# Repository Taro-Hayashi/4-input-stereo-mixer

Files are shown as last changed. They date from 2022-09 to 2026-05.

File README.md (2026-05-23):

# 4入力ステレオミキサー ビルドガイド
- [ご注意](#ご注意)
- [部品リスト](#部品リスト)
- [組み立て](#組み立て)
- [おまけ](#おまけ)
- [ライセンス](#ライセンス)

## ご注意
- Type-A to Type-Cケーブルでのみ給電できます。
- ボリューム調整機能はありません。
- マイクには対応していません。
- 入力端子同士の間隔は1.2cmです。

## 部品リスト
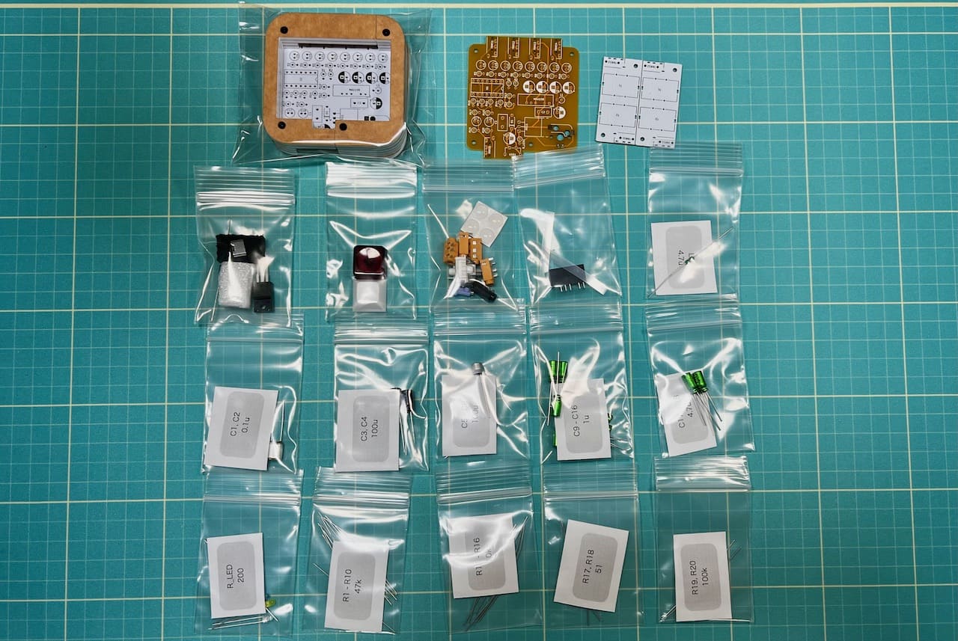
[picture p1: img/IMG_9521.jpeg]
  
|Ref|部品名|数|
|-|-|-|
||メインボード||
||アクリルプレート||
||0.01mm両面テープ||
||5mmM2ねじ|8|
||3x8mmスペーサー|4|
|U1|丸ピンICソケット 14P|1|
||オペアンプ LME49740NA|1|
|MAU108|レギュレーター MAU108|1|
|REG1|レギュレーター NJM7805FA|1|
|USB1|Type-Cコネクタ電源供給用|1|
|TRRS1-5|MJ-4PP-9|5|
|R1-10|47kΩ|10|
|R11-16|10kΩ|6|
|R11-16|10kΩ|6|
|R17,18|51Ω|2|
|R19,20|100kΩ|2|
|R_LED|200Ω|1|
|C1,2|0.1uF フィルムコンデンサー|2|
|C3,4|100uF 電源用電解コンデンサー|2|
|C5-8|100uF OS-CON|4|
|C9-16|1uF オーディオ用無極性コンデンサー|8|
|C17,18|4.7uF オーディオ用無極性コンデンサー|2|
|D1|1N4007|1|
|L1|4.7uH|1|
|LED1|3mmLED 3V 20mA|1|
||キースイッチ|1|
||キーキャップ|1|
||スイッチソケット|1|
||ゴム足|4|

### 工具（必要に応じて準備してください）
|工具名||
|-|-|
|はんだ付け用工具一式||
|精密ドライバー||
|ニッパー|抵抗等の足を切ります。|
|ラジオペンチ|レギュレーターの足を曲げます。ニッパーでも可能です。|
|アクリサンデー ポリケアF70|指紋を拭いたりホコリを付きにくくできます。|
|アクリサンデー 研磨剤|側面を磨いてツルツルにしたり、細かい傷を消すことができます。|
|アクリル接着剤|両面テープの代わりに使うと強固に接着できます。|

## 組み立て
電子部品は番号通りに部品をはんだ付けするだけなのでビルドガイドを見なくても制作可能です。高さが低い順番にはんだ付けする様子を写真で紹介しています。  

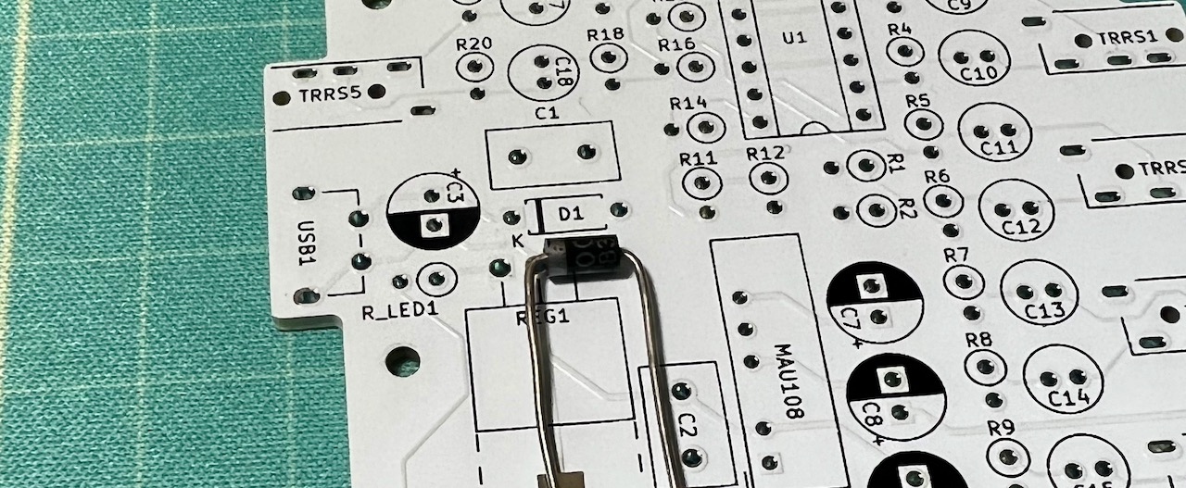
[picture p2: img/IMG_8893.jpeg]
  
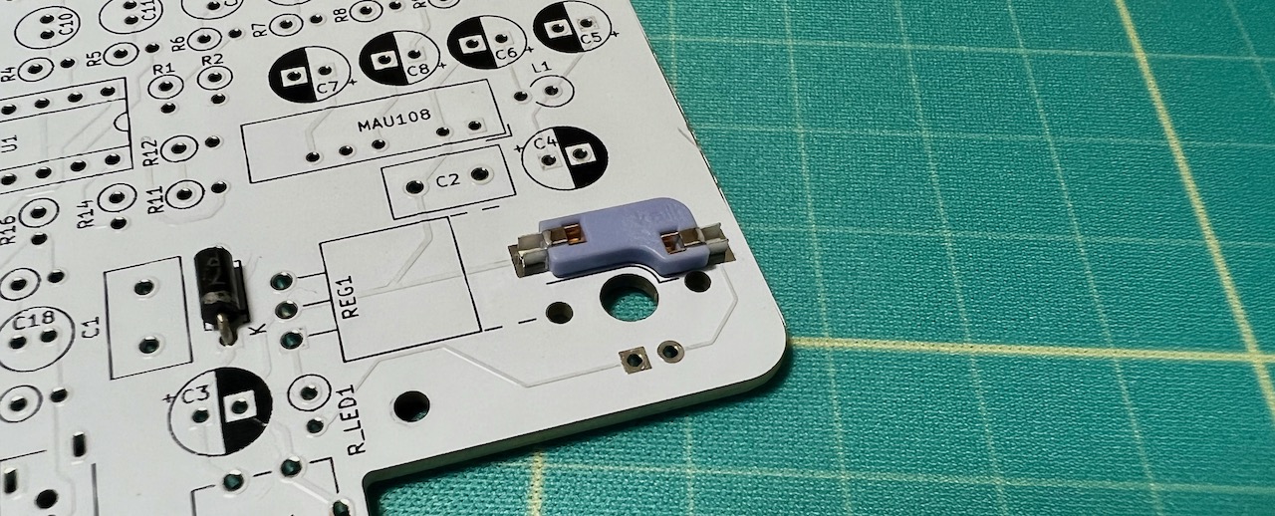
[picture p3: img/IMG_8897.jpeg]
  
Type-Cコネクタはマスキングテープなどで固定するとはんだ付けしやすいです。
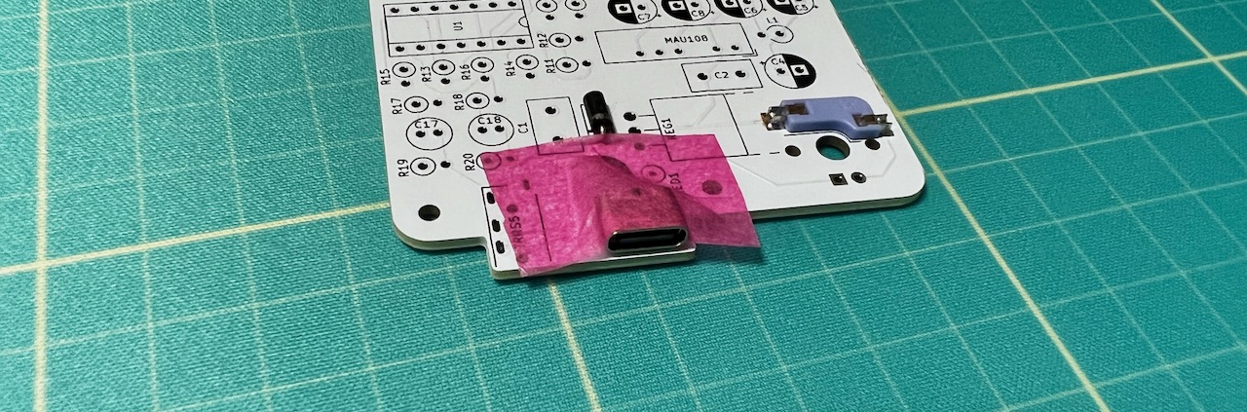
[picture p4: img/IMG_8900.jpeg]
  
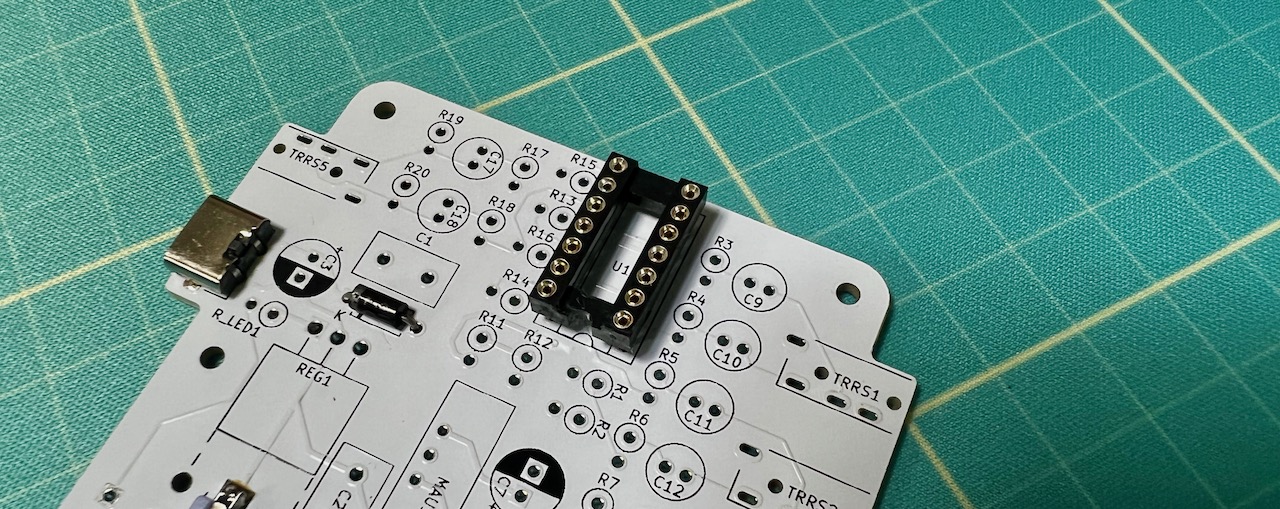
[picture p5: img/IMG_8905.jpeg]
  
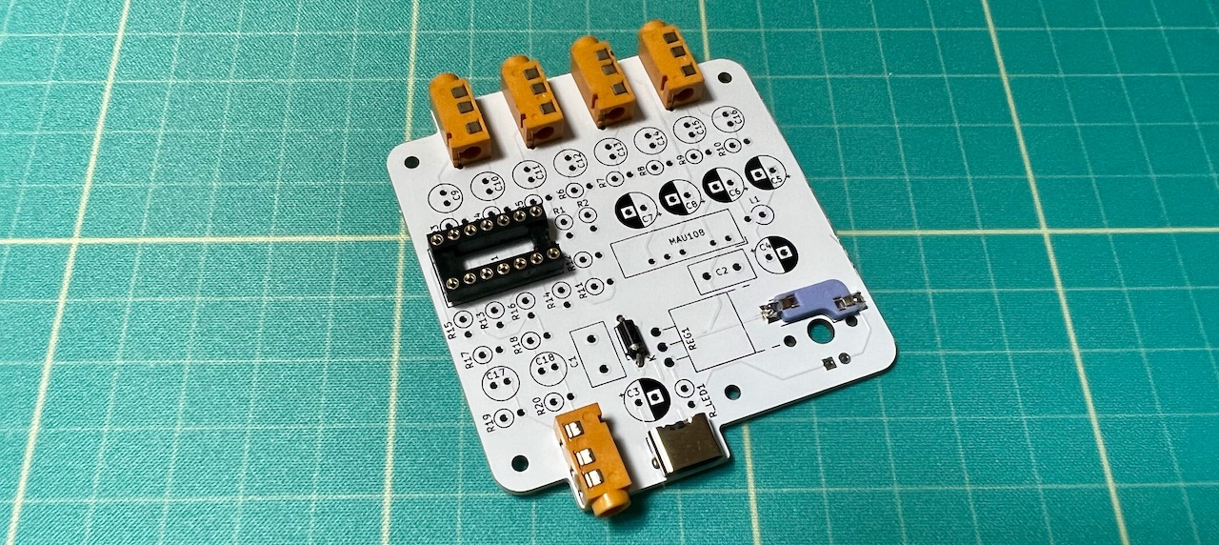
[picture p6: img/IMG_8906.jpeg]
  
OS-CONには極性があります。足が長い方が+（白い側）です。  
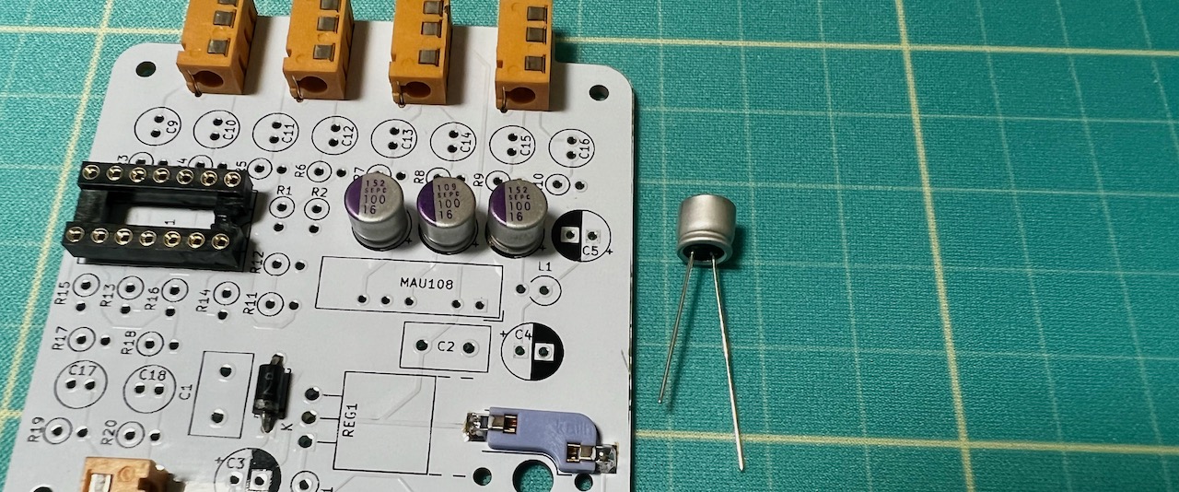
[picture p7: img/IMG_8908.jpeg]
  
レギュレーターの足をラジオペンチ等で曲げます。
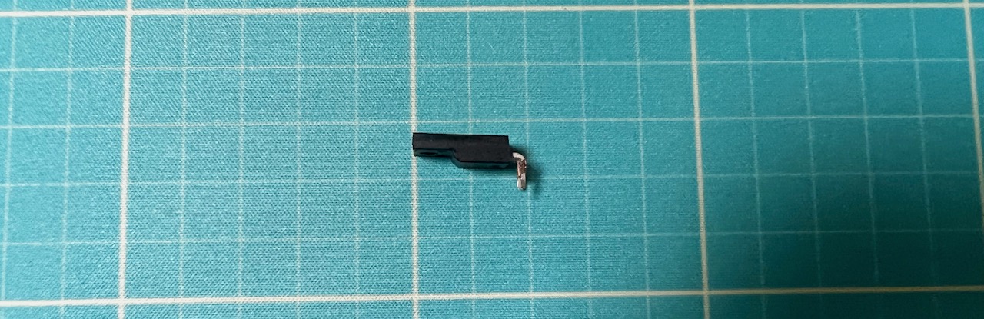
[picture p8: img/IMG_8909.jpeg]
  
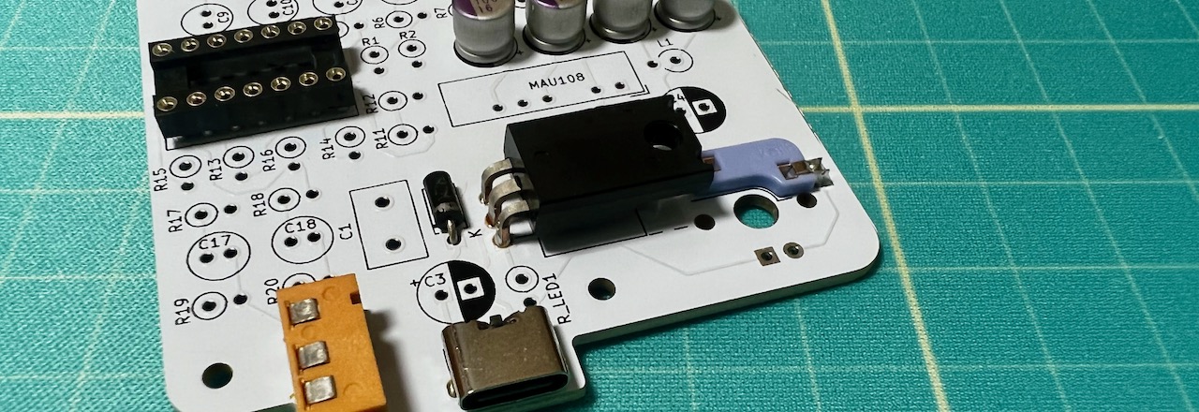
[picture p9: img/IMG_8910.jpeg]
  
コイルや抵抗は写真のように足を曲げて縦に取り付けます。
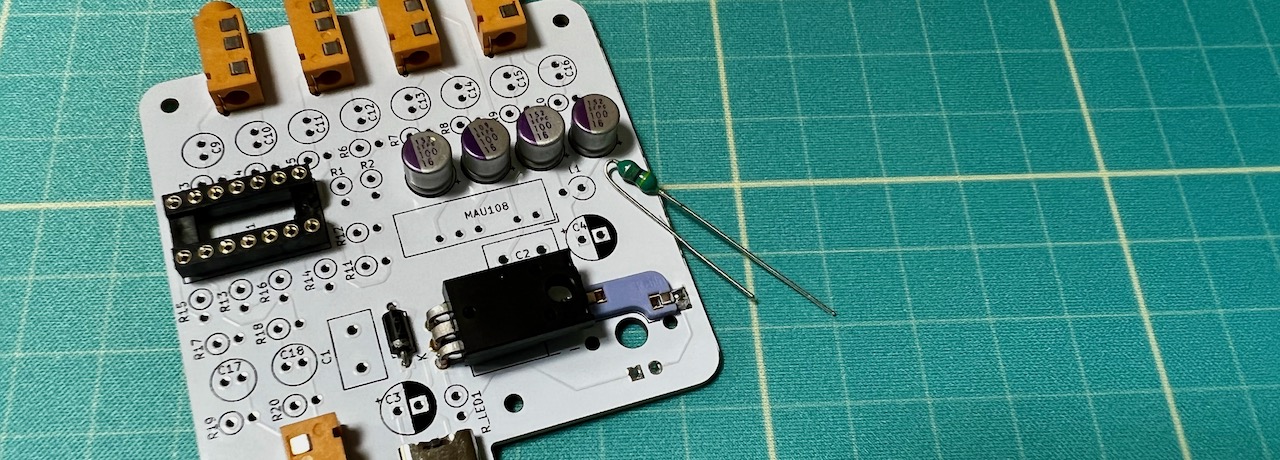
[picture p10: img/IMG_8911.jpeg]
  
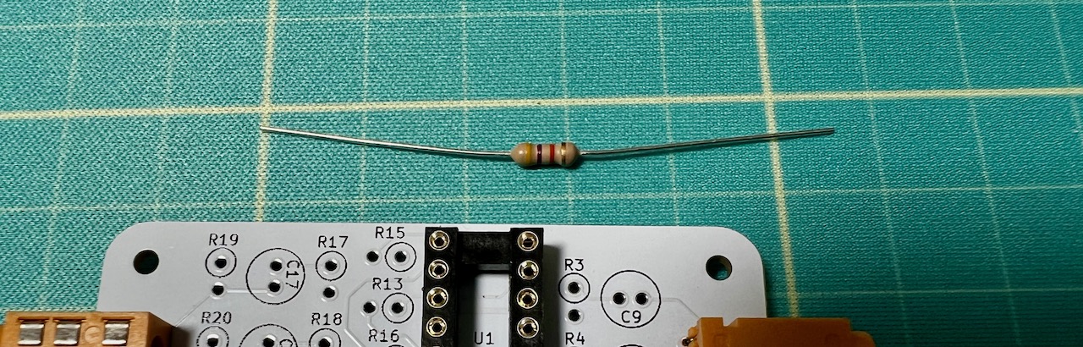
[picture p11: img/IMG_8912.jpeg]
  
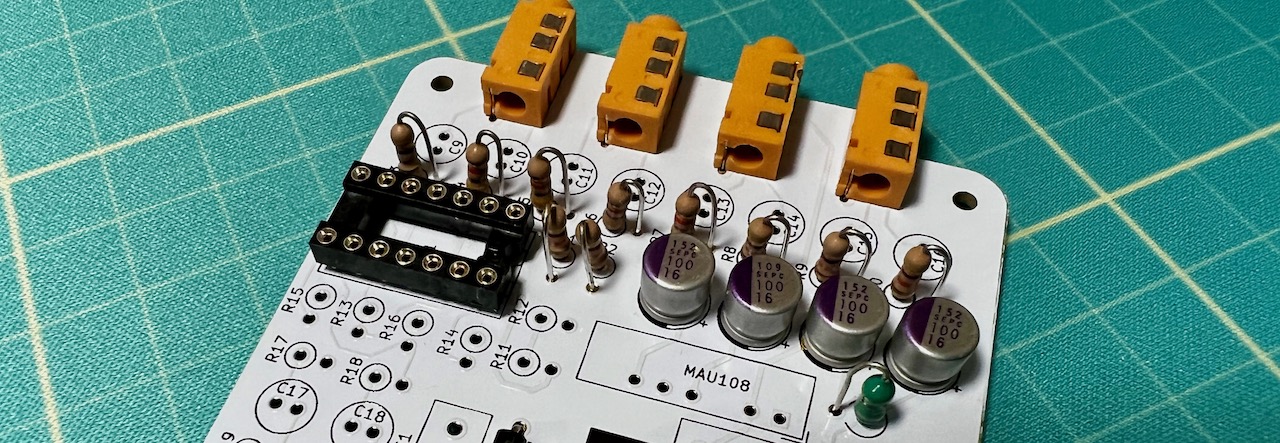
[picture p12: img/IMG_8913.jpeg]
  
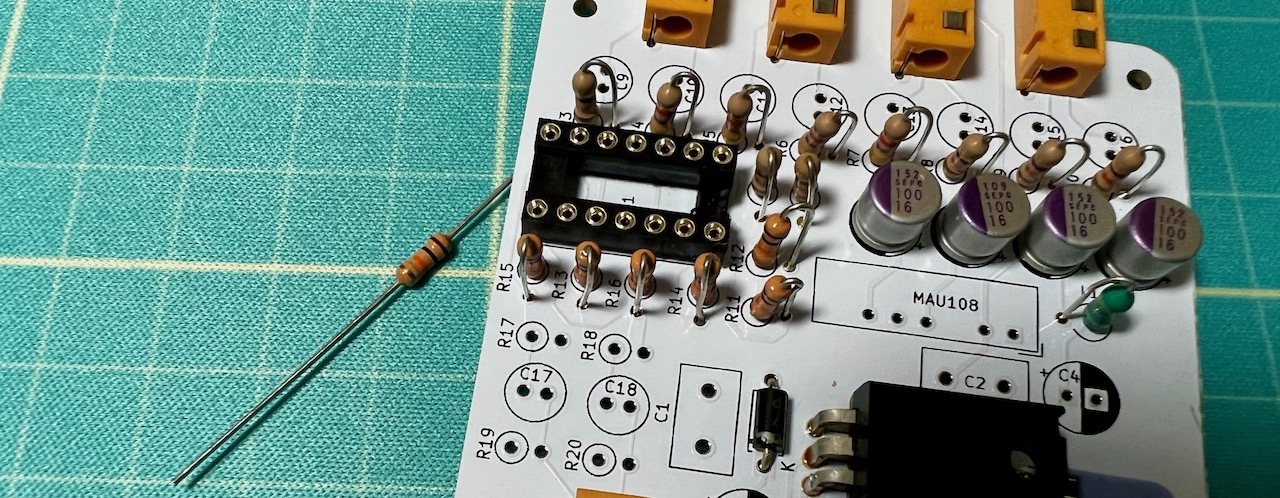
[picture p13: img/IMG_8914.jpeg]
  
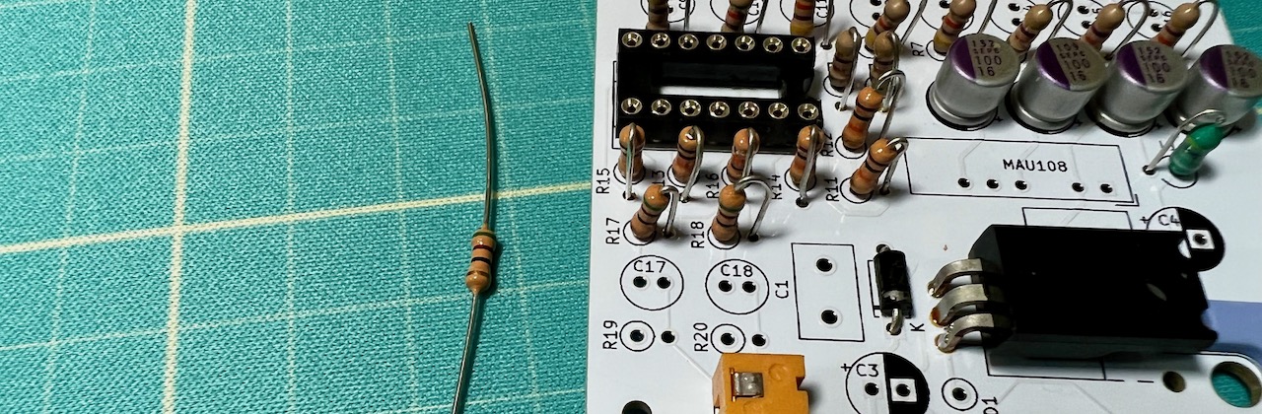
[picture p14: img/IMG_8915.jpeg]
  
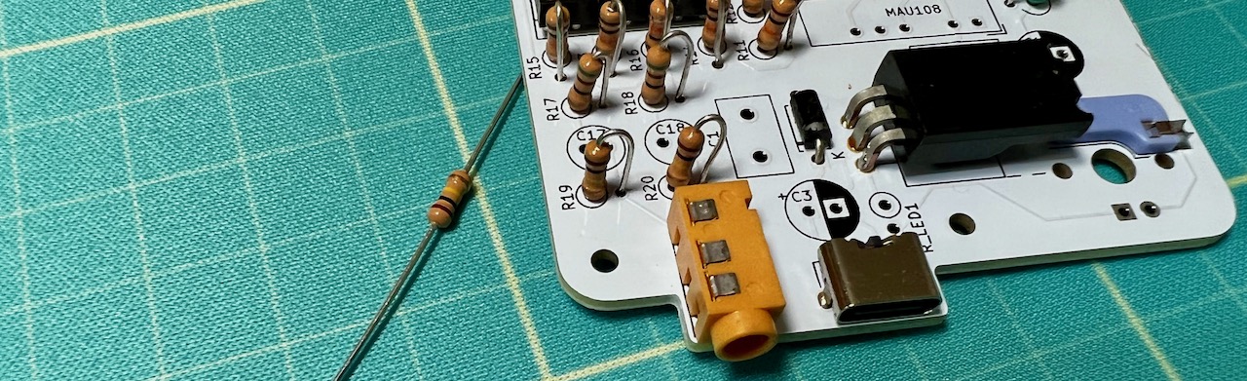
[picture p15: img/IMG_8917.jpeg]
  
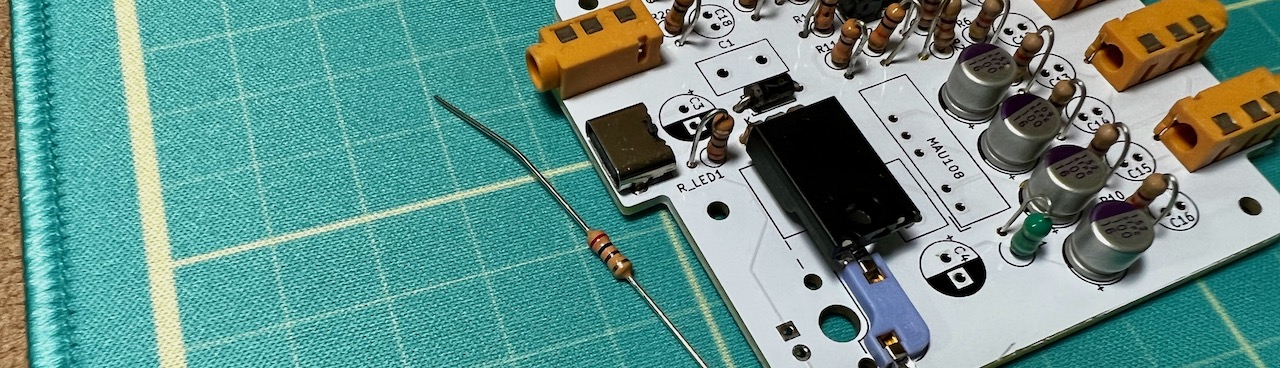
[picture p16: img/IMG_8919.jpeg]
  
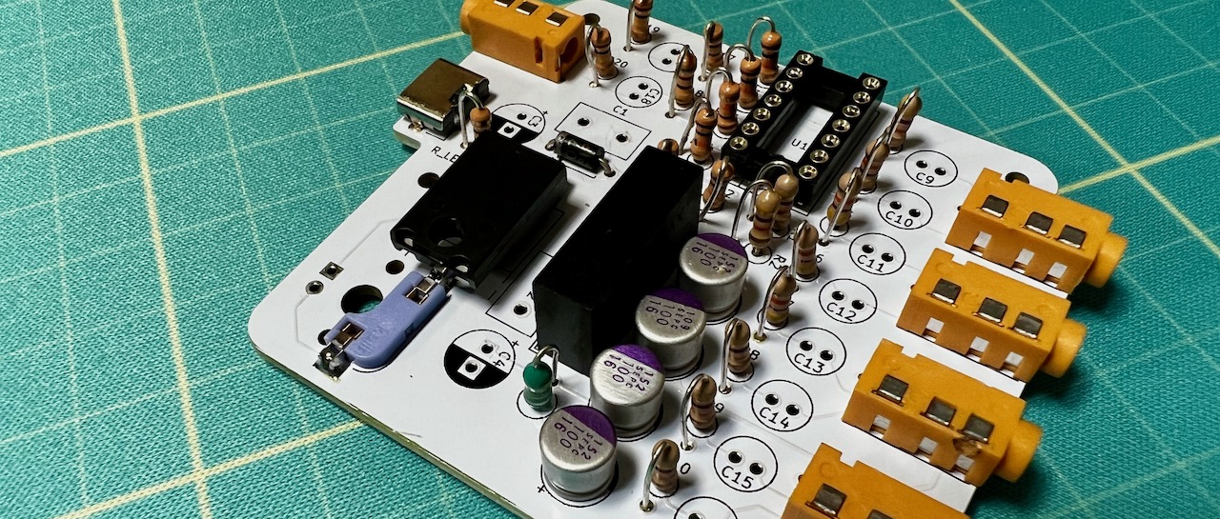
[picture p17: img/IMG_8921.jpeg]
  
フィルムコンデンサーには極性がありません。
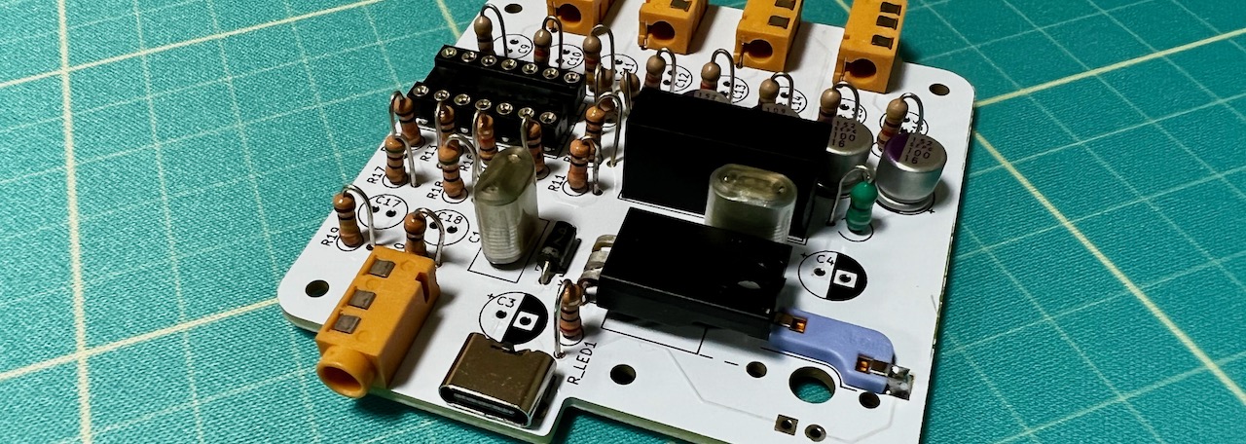
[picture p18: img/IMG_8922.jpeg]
  
電源用電解コンデンサーには極性があります。
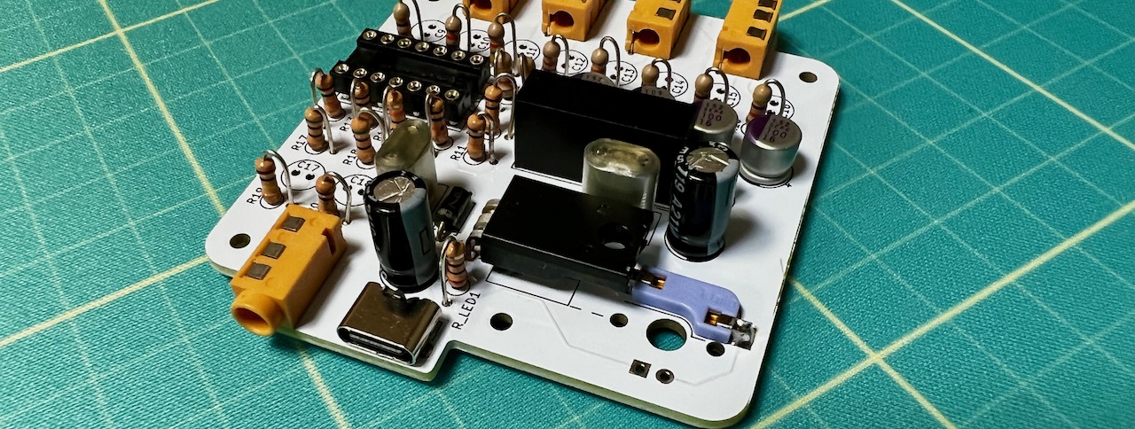
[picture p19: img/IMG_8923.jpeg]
  
オーディオ用コンデンサーには極性がありません。
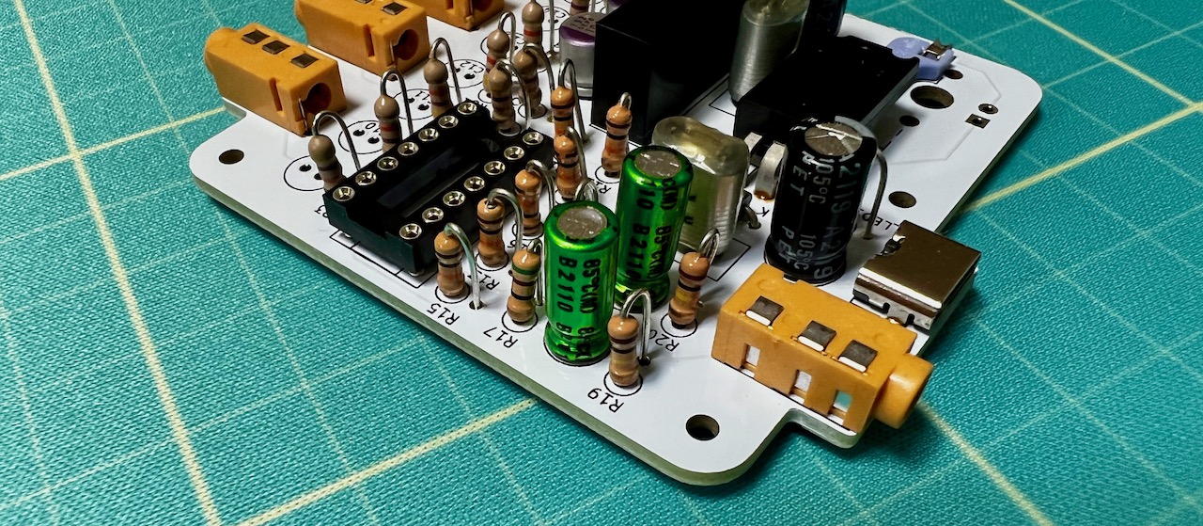
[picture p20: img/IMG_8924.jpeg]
  
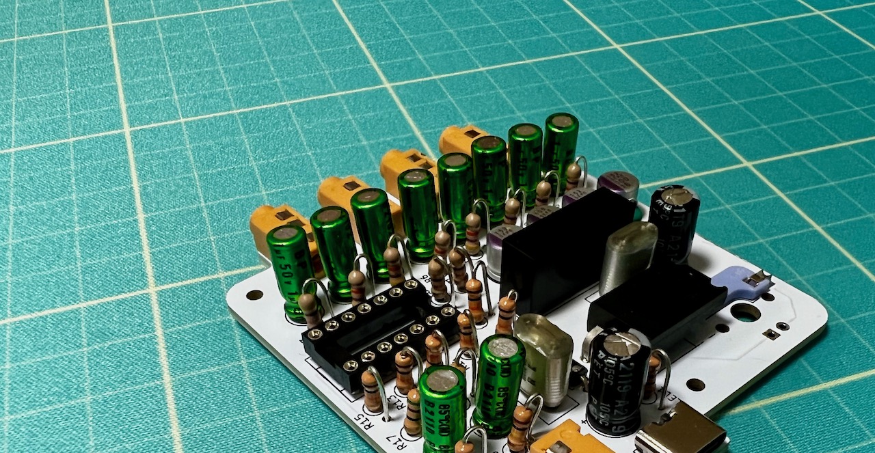
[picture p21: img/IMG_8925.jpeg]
  
すべてのパーツをはんだ付けしたらオペアンプを差し込んで動作を確認しましょう。
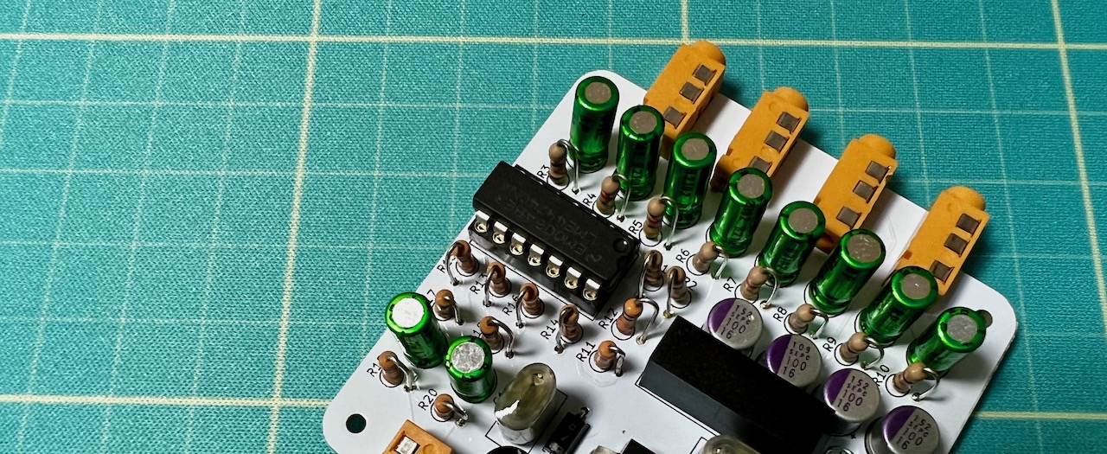
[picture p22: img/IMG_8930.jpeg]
  

アクリルケースを組み立てます。スペーサー4つをネジで取り付けます。
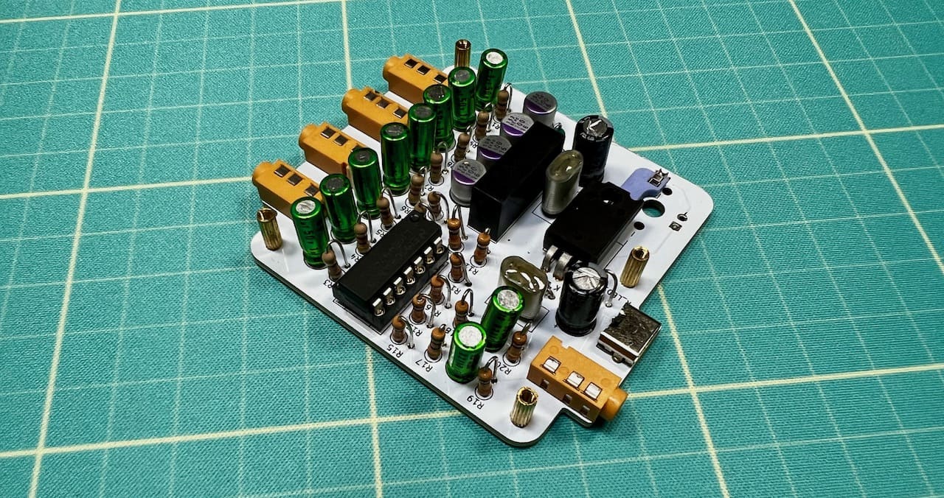
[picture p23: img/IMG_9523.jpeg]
  

アクリルプレートから保護フィルムを剥がしのせていきます。順番は写真を参考にしてください。
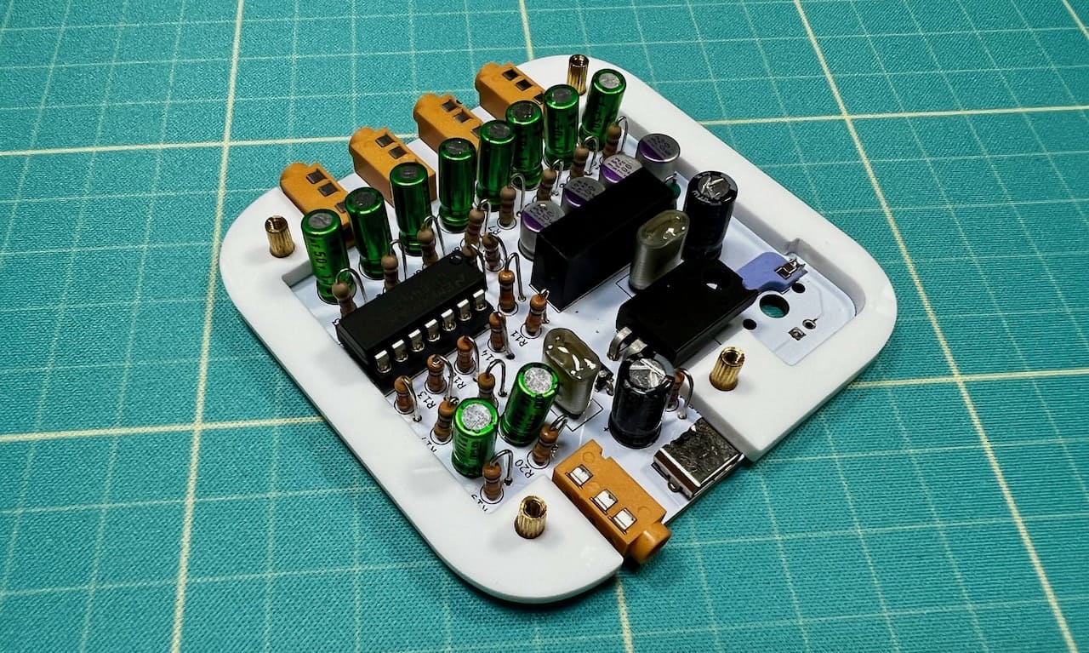
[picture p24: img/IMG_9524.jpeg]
  
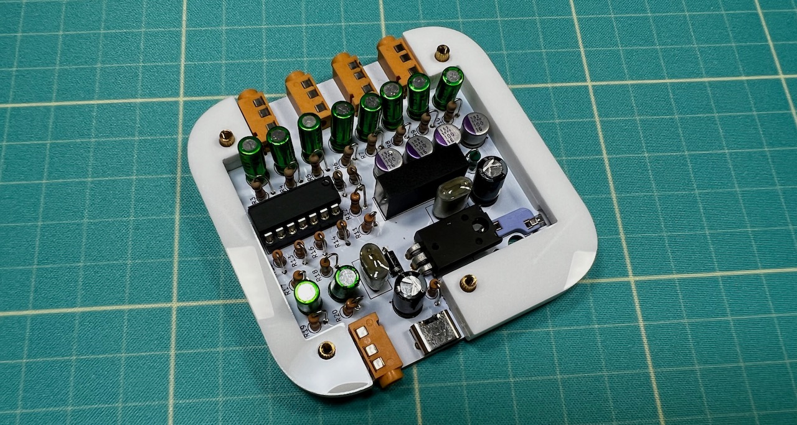
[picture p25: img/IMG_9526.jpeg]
  
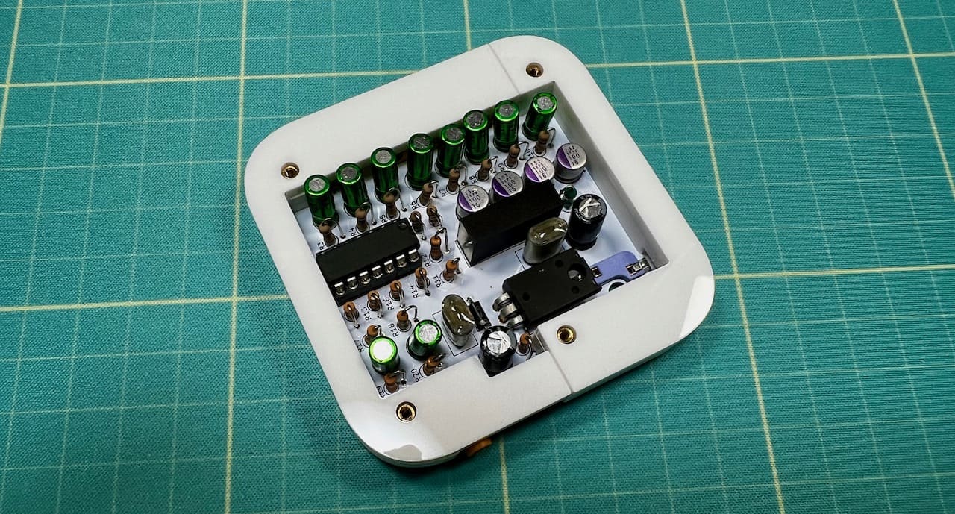
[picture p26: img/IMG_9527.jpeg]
  
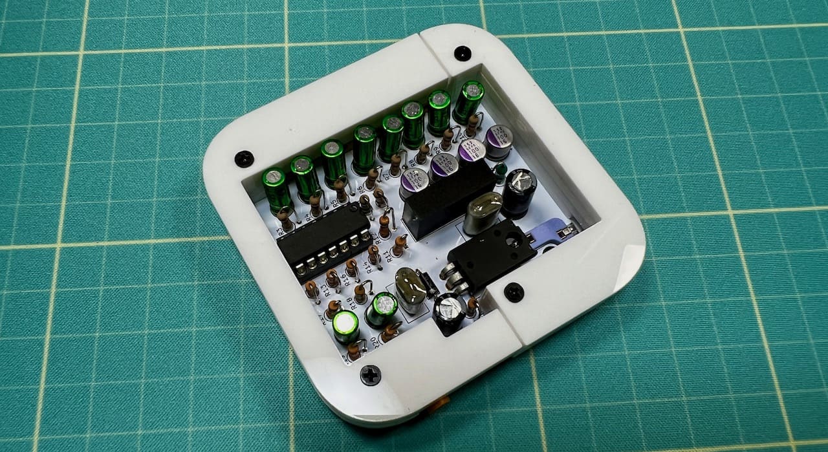
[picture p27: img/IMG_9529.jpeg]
  
ネジは締めきらず、微調整できるようにしておくと側面を綺麗に揃えやすいです。  
  
裏返して片面を剥がした両面テープを貼ります。皮脂が付いていると剥がれやすくなるので気をつけてください。  
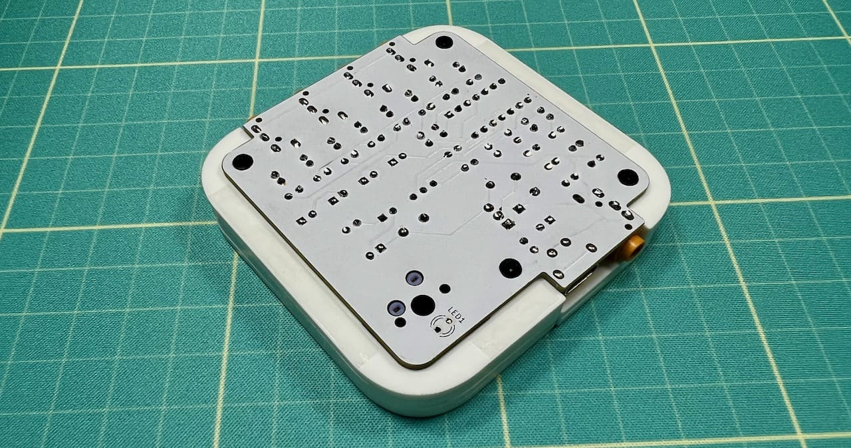
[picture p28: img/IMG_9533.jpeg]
  

両面テープをはがし、側面のカーブを合わせて貼り付けます。
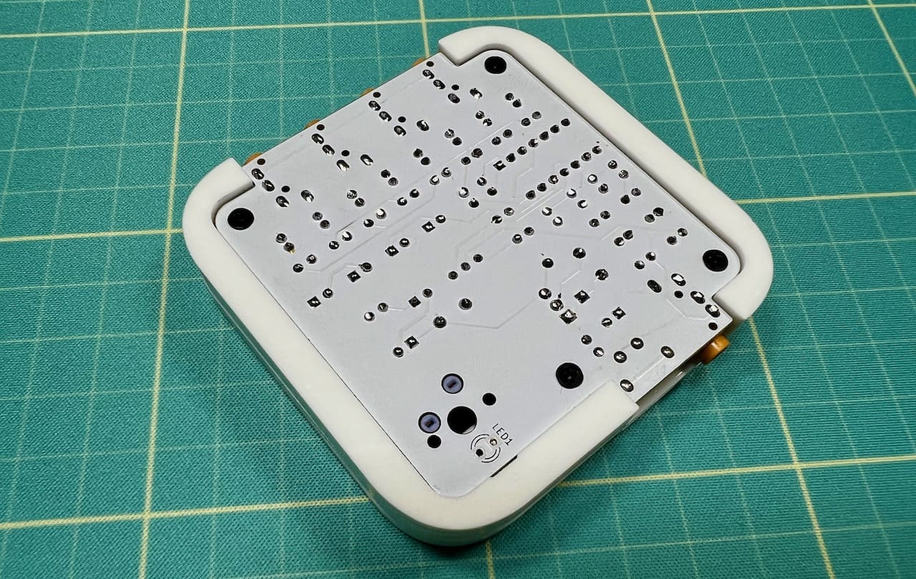
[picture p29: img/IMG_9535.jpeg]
  
残りのプレートも同じように貼り付けます。
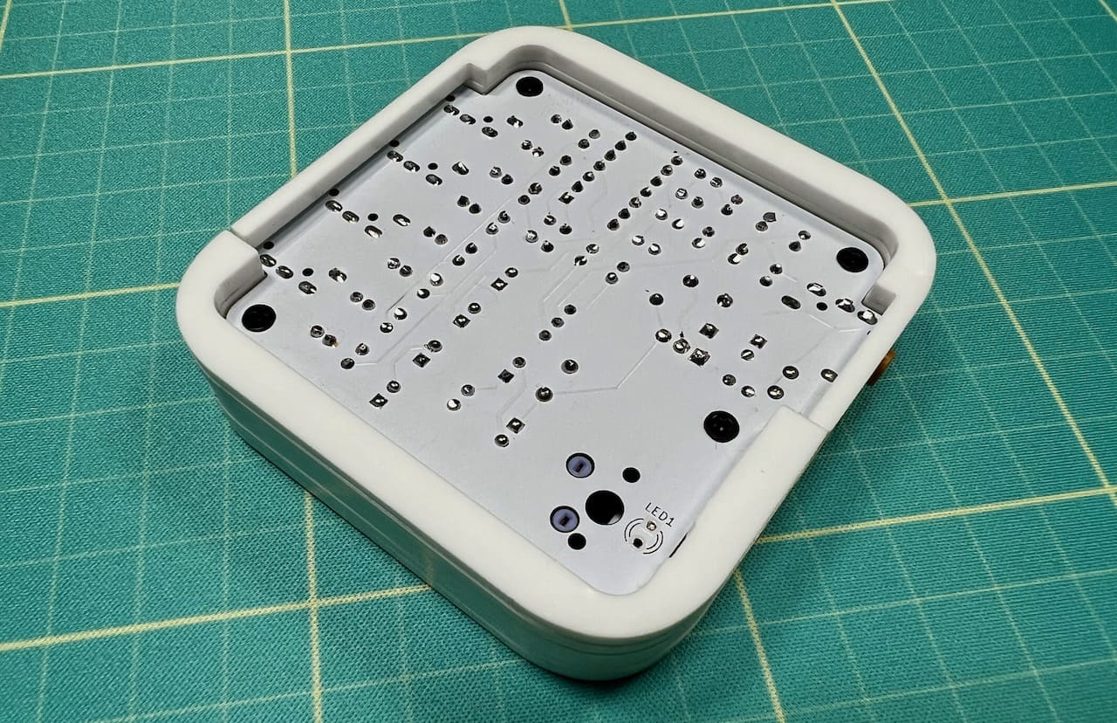
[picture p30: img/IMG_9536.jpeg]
  
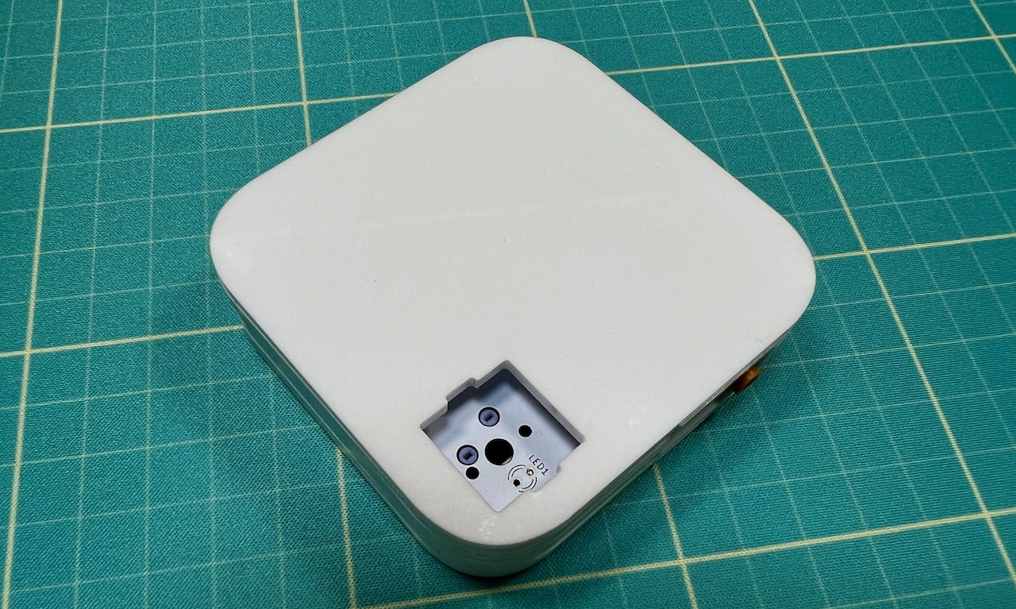
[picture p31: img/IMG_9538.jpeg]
  
好みのキースイッチを差し込んで、ゴム足とキーキャップを付けたら完成です。 
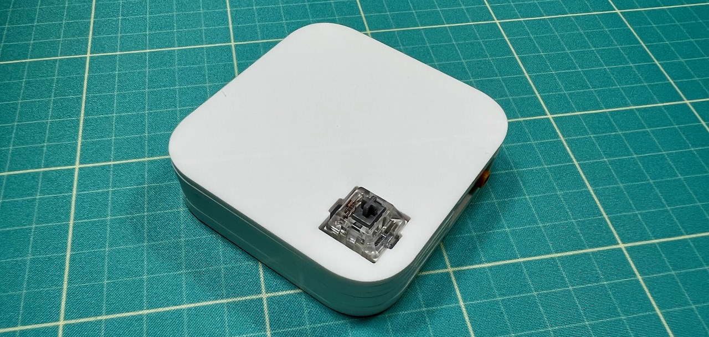
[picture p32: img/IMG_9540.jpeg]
  
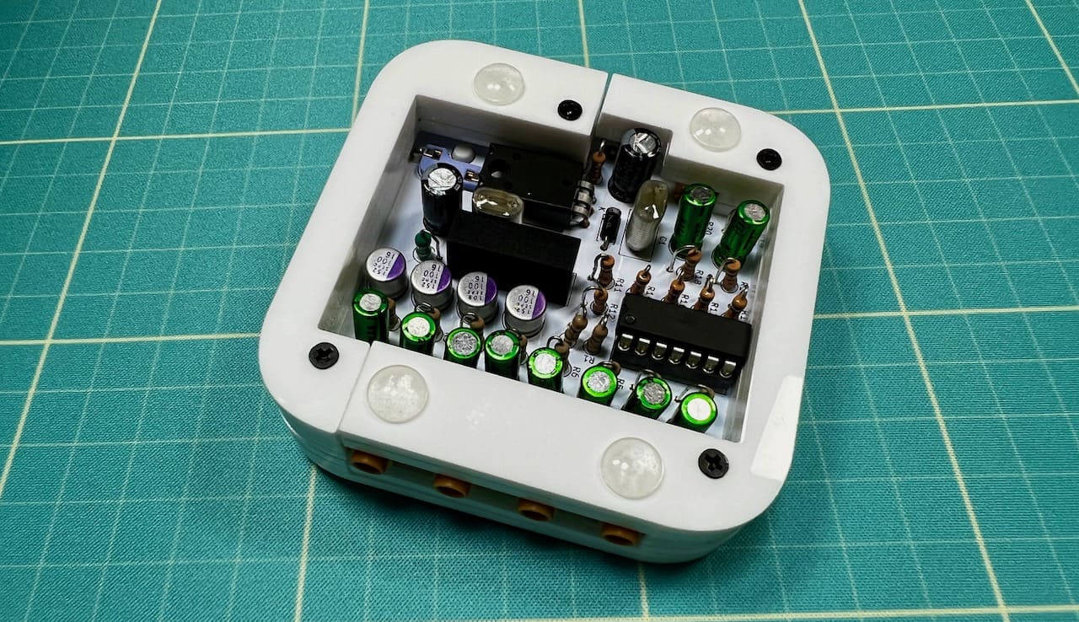
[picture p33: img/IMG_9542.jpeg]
  
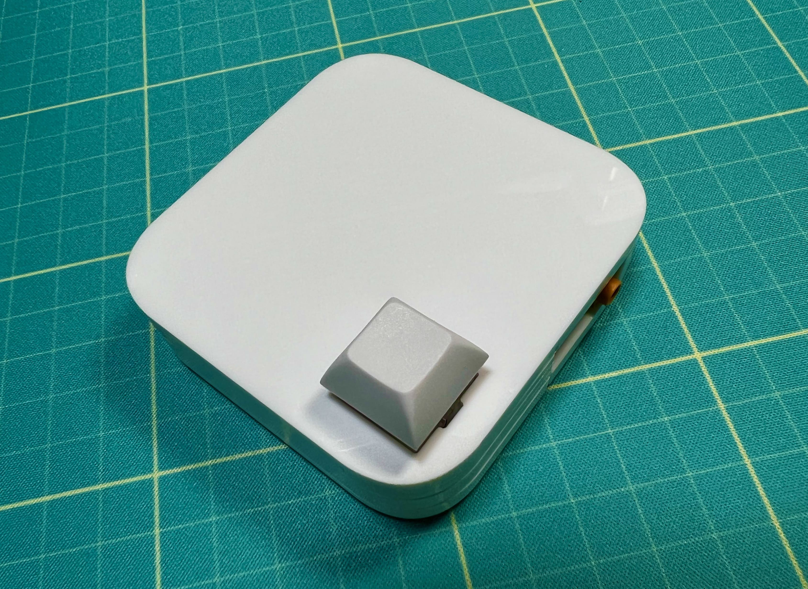
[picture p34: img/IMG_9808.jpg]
 

## おまけ
### LEDを光らせる
キースイッチによってはLEDを取り付ける穴が開いていないことがあります。また、LEDをはんだ付けするとキースイッチを外せなくなります。  
裏面のネジを外してプレートを取り除き、キースイッチの上からLEDを差します。写真と同じように、長い方の足が四角のパッドから出るようにしてください。  
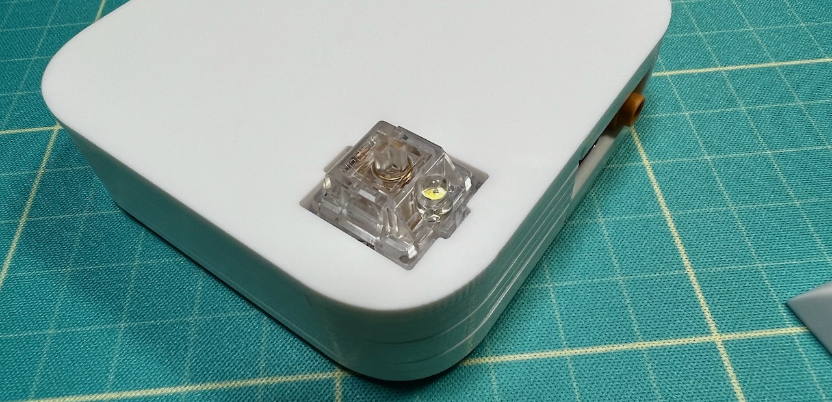
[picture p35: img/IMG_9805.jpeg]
  
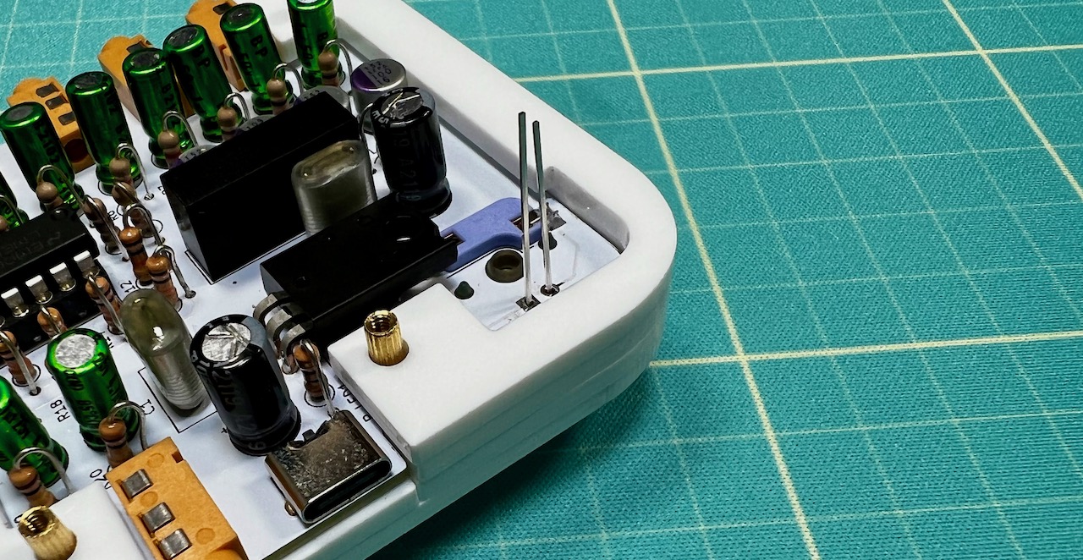
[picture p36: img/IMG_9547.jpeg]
  
はんだ付けして足を切り、プレートを戻します。
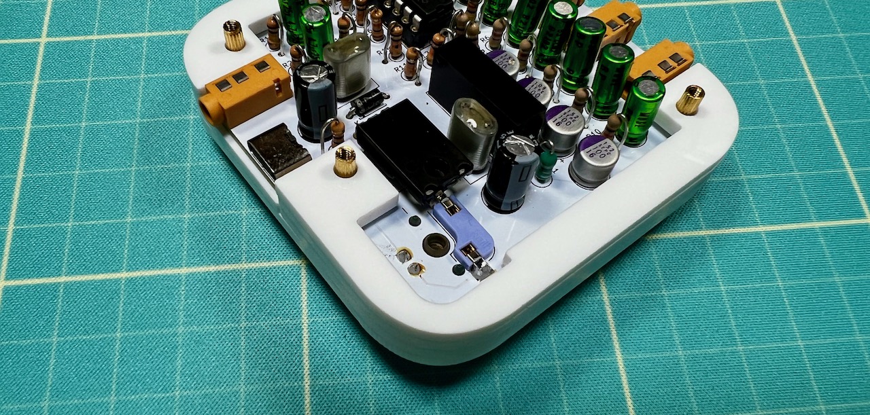
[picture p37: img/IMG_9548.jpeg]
  
USBを繋いでスイッチを押すとLEDが発光します。

### ノイズ対策
ジリジリしたノイズが乗っている場合、グラウンドループアイソレーターを使うことで解決することがあります。
おまけの基板に別売りのTRRSジャック（[MJ-4PP-9](https://akizukidenshi.com/catalog/g/gC-06070/)）とトランス（[AT129](https://akizukidenshi.com/catalog/g/gP-14522/)）をはんだ付けすると作ることができます。
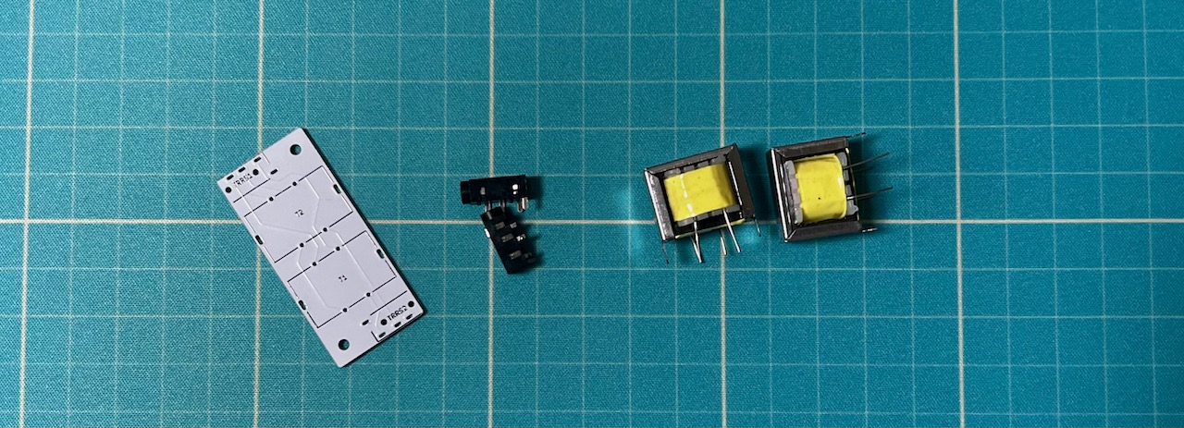
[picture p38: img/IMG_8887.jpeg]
  
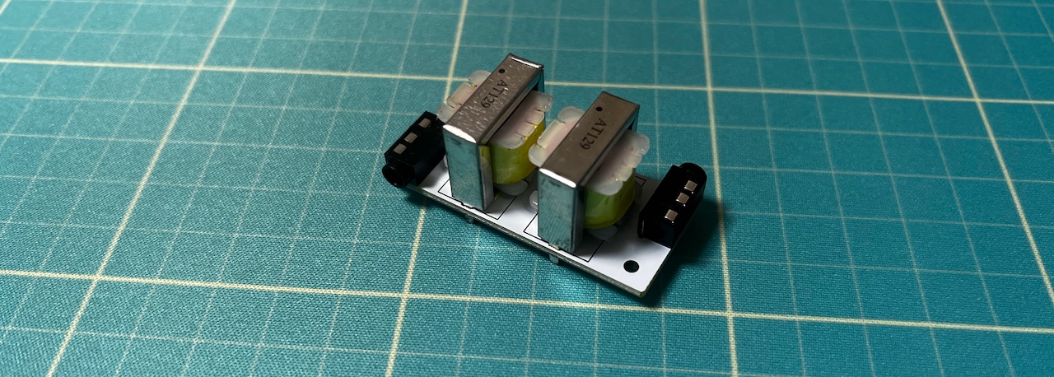
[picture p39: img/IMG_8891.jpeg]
  
検索すると市販のものもたくさん出てくるので好きなものを使ってください。

#### KiCad ファイル
- [KiCad](KiCad)

#### ガーバー
- [gerber](gerber)

## 販売ページ
- [BOOTH](https://tarohayashi.booth.pm/items/4152188)

## ライセンス
KiCadファイル（`KiCad/`）とガーバーファイル（`gerber/`）は、CC0 1.0 Universalでパブリックドメインに提供します。

これらのファイルは、表記なしで利用、改変、製造、配布、販売できます。

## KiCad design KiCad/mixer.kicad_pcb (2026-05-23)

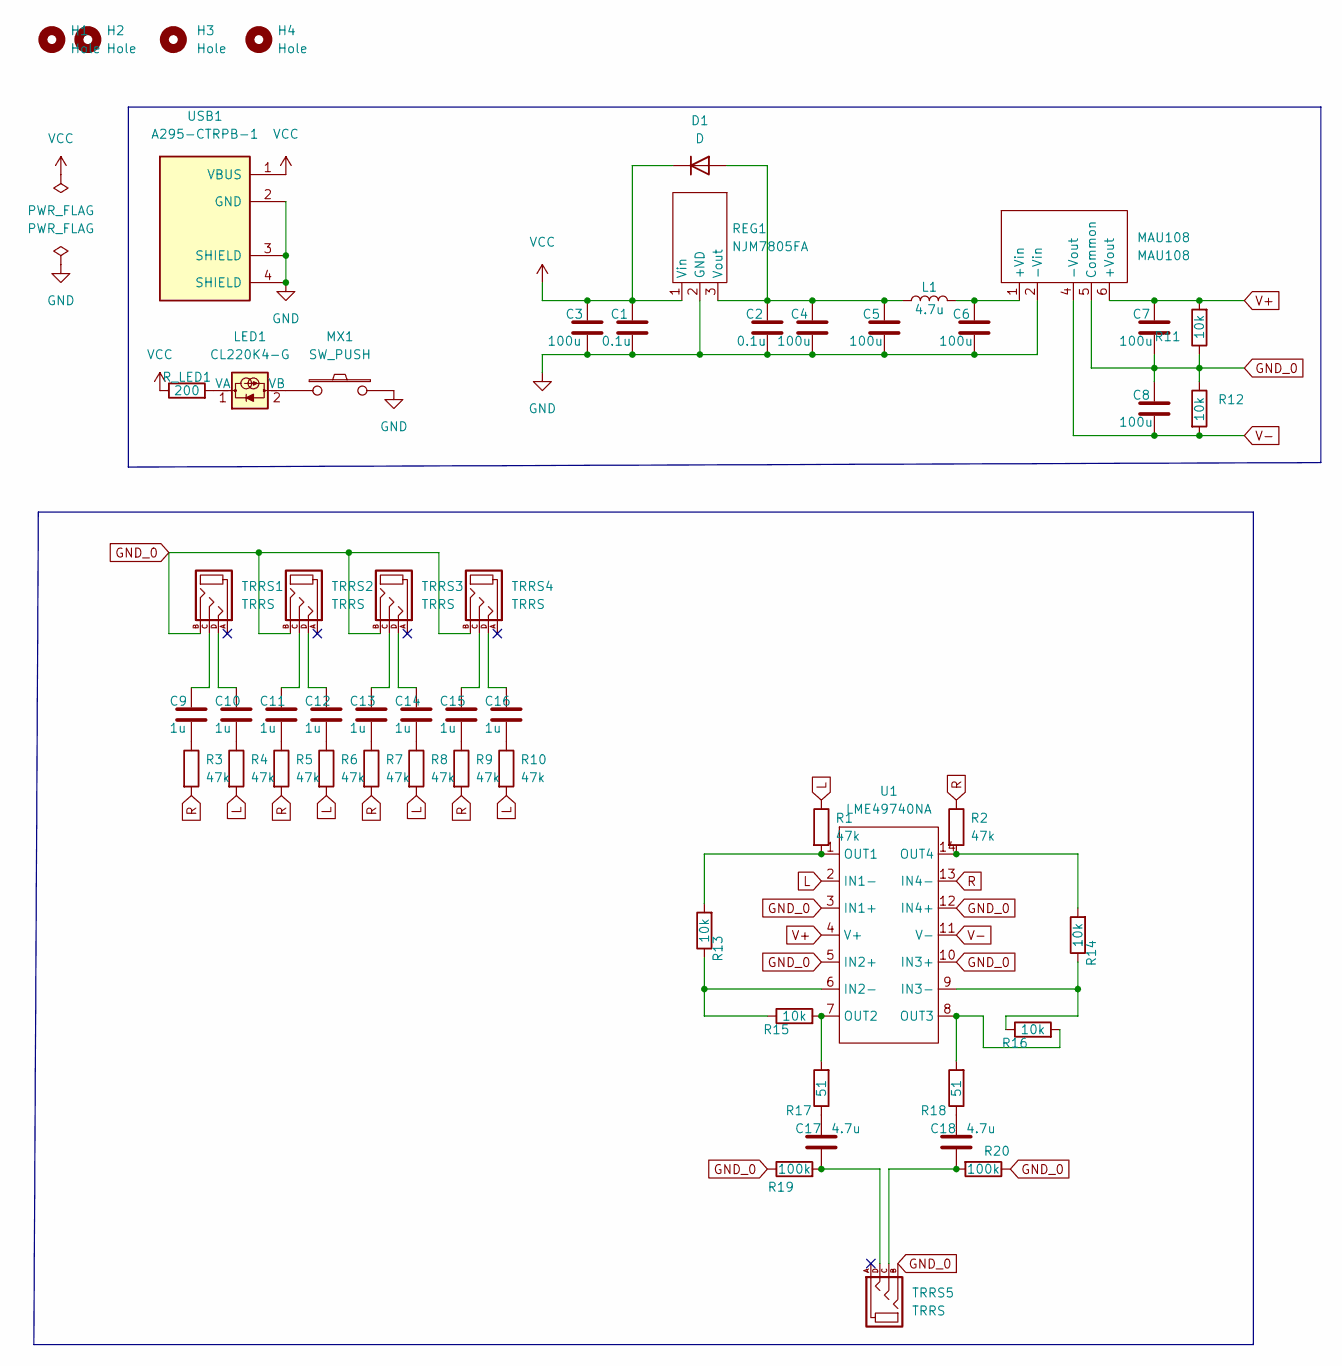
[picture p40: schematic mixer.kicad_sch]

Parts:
C1, C2: 0.1u; C_Disc_D9.0mm_W5.0mm_P5.00mm
C3, C4, C5, C6, C7, C8: 100u; CP_Radial_D6.3mm_P2.50mm
C9, C10, C11, C12, C13, C14, C15, C16: 1u; C_Radial_D5.0mm_H11.0mm_P2.00mm
C17, C18: 4.7u; C_Radial_D5.0mm_H11.0mm_P2.00mm
D1: D; D_A-405_P7.62mm_Horizontal
H1, H2, H3, H4: Hole; Hole_2.2mm_M2
L1: 4.7u; L_Axial_L7.0mm_D3.3mm_P2.54mm_Vertical_Fastron_MICC
LED1: CL220K4-G; LED_D3.0mm
MAU108: MAU108; Converter_DCDC_Murata_NMAxxxxSC_THT
MX1: SW_PUSH; MXOnly-1U-Hotswap
R1, R2, R3, R4, R5, R6, R7, R8, R9, R10: 47k; R_Axial_DIN0207_L6.3mm_D2.5mm_P2.54mm_Vertical
R11, R12, R13, R14, R15, R16: 10k; R_Axial_DIN0207_L6.3mm_D2.5mm_P2.54mm_Vertical
R17, R18: 51; R_Axial_DIN0207_L6.3mm_D2.5mm_P2.54mm_Vertical
R19, R20: 100k; R_Axial_DIN0207_L6.3mm_D2.5mm_P2.54mm_Vertical
REG1: NJM7805FA; TO-220F-3_Horizontal_TabUp
R_LED1: 200; R_Axial_DIN0207_L6.3mm_D2.5mm_P2.54mm_Vertical
TRRS1, TRRS2, TRRS3, TRRS4, TRRS5: TRRS
U1: LME49740NA; DIP-14_W7.62mm_Socket
USB1: A295-CTRPB-1

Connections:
GND: C1.2, C2.2, C3.2, C4.2, C5.2, C6.2, MAU108.2 (-Vin), MX1.2, REG1.2 (GND), USB1.2 (GND), USB1.3 (SHIELD), USB1.4 (SHIELD)
GND_0: C7.2, C8.1, MAU108.5 (Common), R11.1, R12.1, R19.1, R20.1, TRRS1.B, TRRS2.B, TRRS3.B, TRRS4.B, TRRS5.B, U1.3 (IN1+), U1.5 (IN2+), U1.10 (IN3+), U1.12 (IN4+)
L: R1.1, R4.2, R6.2, R8.2, R10.2, U1.2 (IN1-)
unnamed: C2.1, C4.1, C5.1, D1.2 (A), L1.1, REG1.3 (Vout)
unnamed: C6.1, L1.2, MAU108.1 (+Vin)
unnamed: C9.1, TRRS1.C
unnamed: C9.2, R3.1
unnamed: C10.1, TRRS1.D
unnamed: C10.2, R4.1
unnamed: C11.1, TRRS2.C
unnamed: C11.2, R5.1
unnamed: C12.1, TRRS2.D
unnamed: C12.2, R6.1
unnamed: C13.1, TRRS3.C
unnamed: C13.2, R7.1
unnamed: C14.1, TRRS3.D
unnamed: C14.2, R8.1
unnamed: C15.1, TRRS4.C
unnamed: C15.2, R9.1
unnamed: C16.1, TRRS4.D
unnamed: C16.2, R10.1
unnamed: C17.1, R17.1
unnamed: C17.2, R19.2, TRRS5.D
unnamed: C18.1, R18.1
unnamed: C18.2, R20.2, TRRS5.C
unnamed: LED1.2 (VB), MX1.1
unnamed: R1.2, R13.2, U1.1 (OUT1)
unnamed: R13.1, R15.1, U1.6 (IN2-)
unnamed: R14.1, R16.1, U1.9 (IN3-)
unnamed: R2.2, R14.2, U1.14 (OUT4)
unnamed: R15.2, R17.2, U1.7 (OUT2)
unnamed: R16.2, R18.2, U1.8 (OUT3)
unnamed: LED1.1 (VA), R_LED1.2
R: R2.1, R3.2, R5.2, R7.2, R9.2, U1.13 (IN4-)
V+: C7.1, MAU108.6 (+Vout), R11.2, U1.4 (V+)
V-: C8.2, MAU108.4 (-Vout), R12.2, U1.11 (V-)
VCC: C1.1, C3.1, D1.1 (K), REG1.1 (Vin), R_LED1.1, USB1.1 (VBUS)

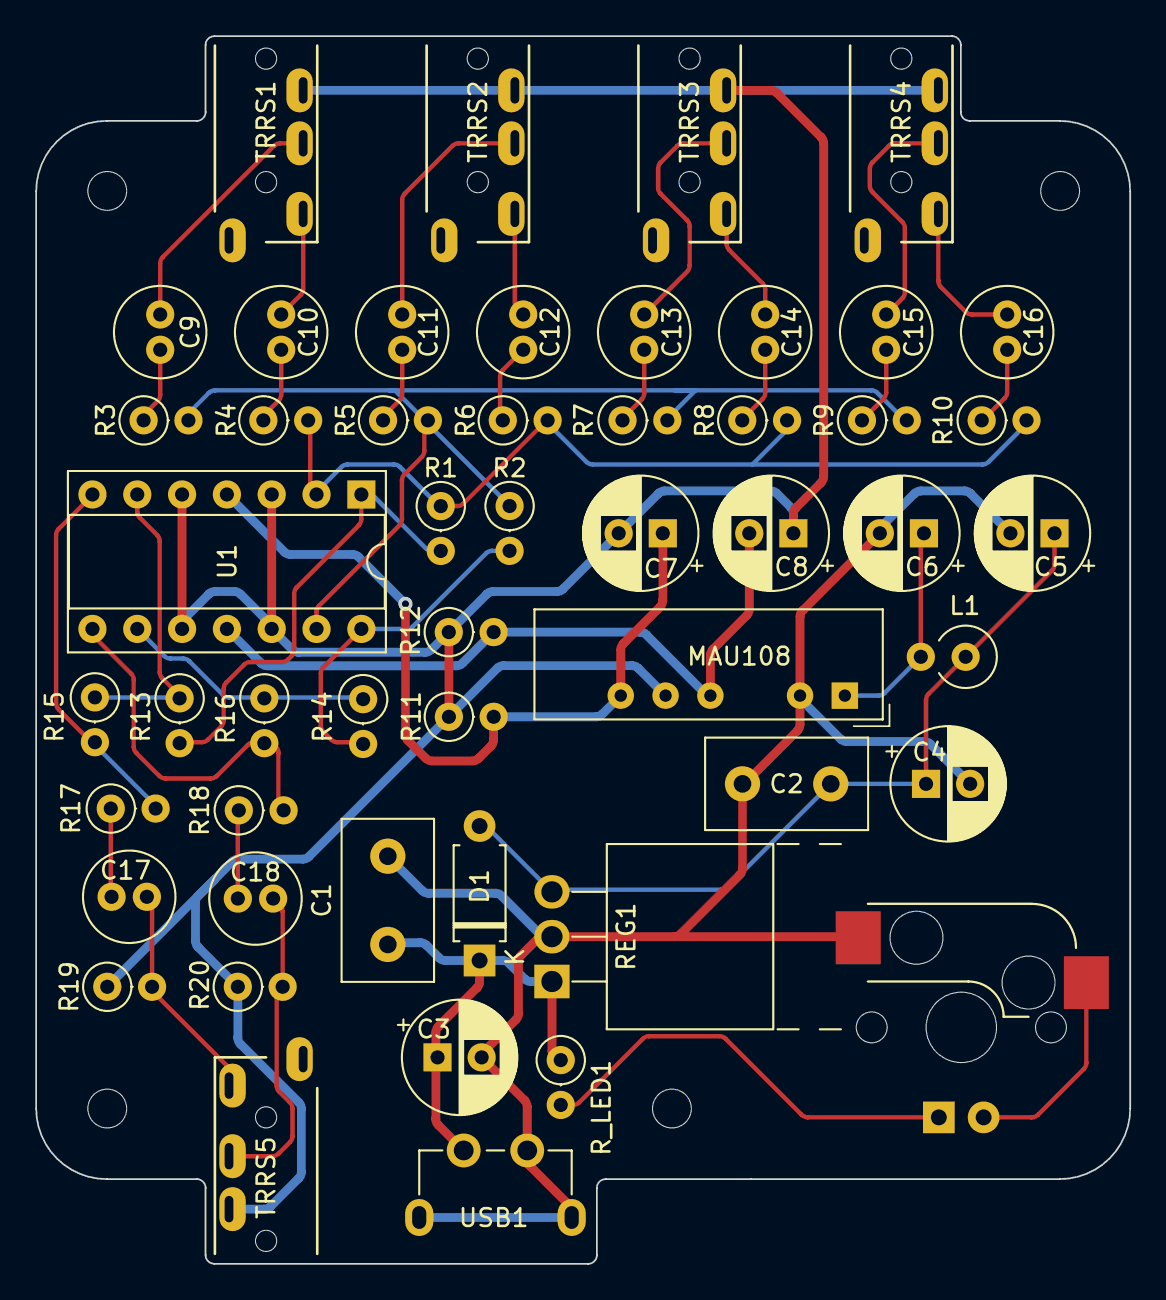
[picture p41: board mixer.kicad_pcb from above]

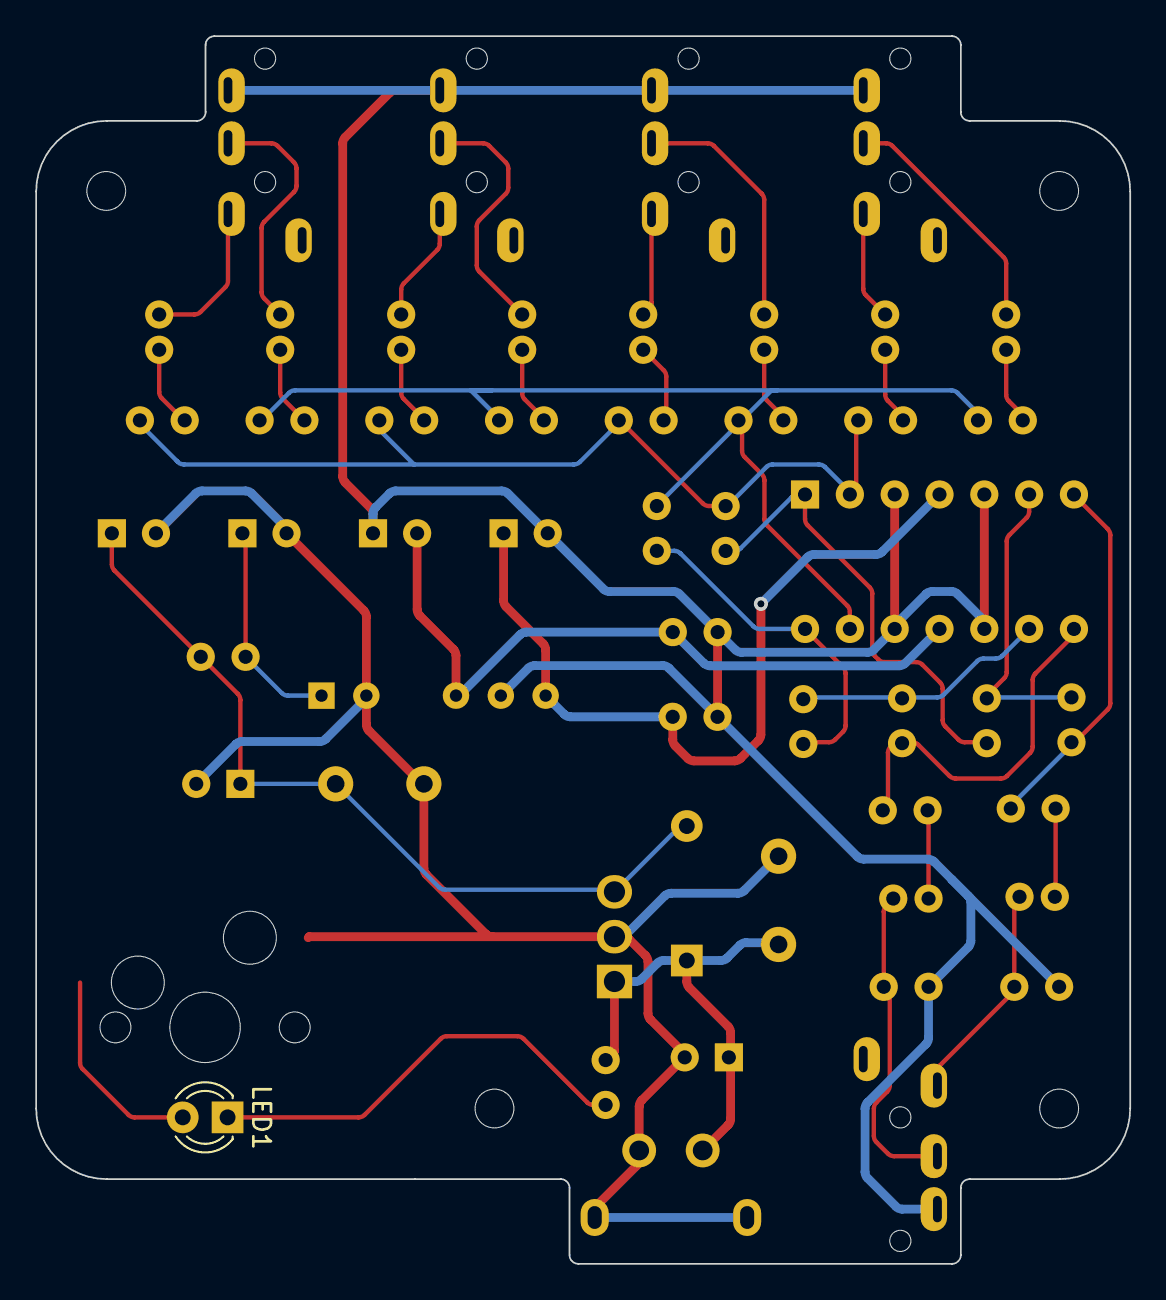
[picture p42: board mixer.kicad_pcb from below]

Board: 2 copper layers, 62.0 x 69.6 mm, 56 parts (2 on the bottom side), 37 nets.

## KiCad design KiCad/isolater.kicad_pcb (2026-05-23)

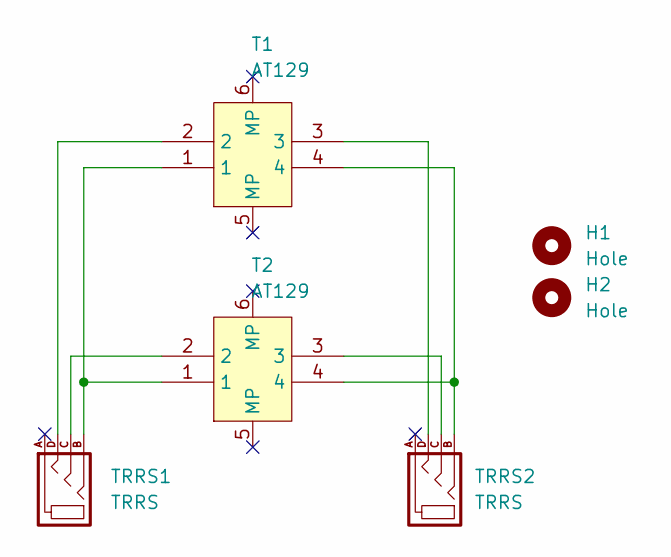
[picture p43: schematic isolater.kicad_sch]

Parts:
H1, H2: Hole; Hole_2.2mm_M2
T1, T2: AT129
TRRS1, TRRS2: TRRS

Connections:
unnamed: T1.1, T2.1, TRRS1.B
unnamed: T1.2, TRRS1.D
unnamed: T1.3, TRRS2.D
unnamed: T1.4, T2.4, TRRS2.B
unnamed: T2.2, TRRS1.C
unnamed: T2.3, TRRS2.C

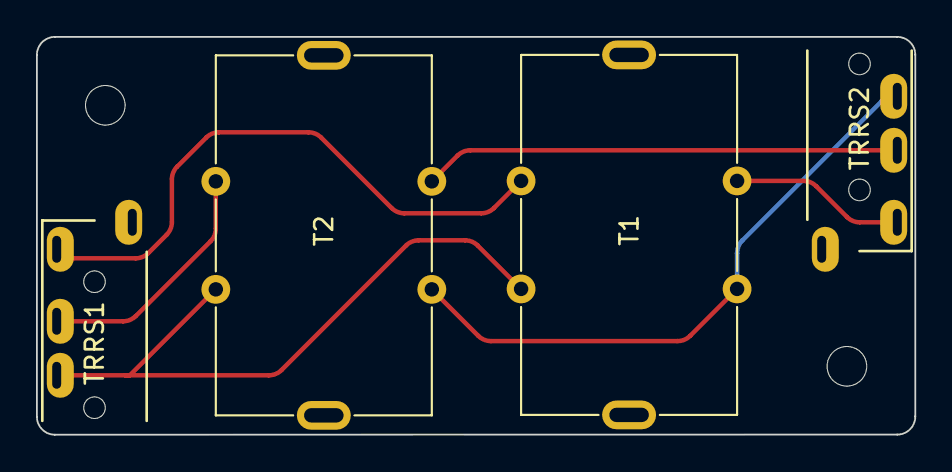
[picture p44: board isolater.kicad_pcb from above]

Board: 2 copper layers, 48.8 x 22.1 mm, 6 parts (0 on the bottom side), 6 nets.
